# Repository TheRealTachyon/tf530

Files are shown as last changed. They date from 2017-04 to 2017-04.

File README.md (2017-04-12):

# Fork pulled by Tachyon to preserve the project. Commits accepted.
# Original file and comments follow
#  --------------------------------------------------------

# TF530 (Archived)

## I am no longer working on this. Do not ask for support.

This repository contains all the files needed to produce a copy of my accelerator board.

The CPLD Required is a XC9572XL-10VQ64

Everything in this repository is released under the GNU GPLv2. You may create or base commercial PCBs from the work in this repository but you must make the sources for all derivative work available. 

## Firmware / Requirements

  * Xilinx ISE, 14.7 (the final version - other versions may work but this is the one I support)
  * JTAG Adaptor

[For more information visit my channel](https://www.youtube.com/c/TerribleFire)

##License

This project and all the files contained are released under the GNU GPLv2. If you build a modified version of the board you must supply the end user with all the sources (this can be a web link).

##The TerribleFire 530 board (Revision 2)

This board is now in Beta. It may not work in all circumstances but it has been verified to boot AmigaOS 1.3, 2.05 and 3.1 and run various games and desktop apps at 25Mhz. Operation is not guarunteed to be crash free but will work in most "happy path" situations.

I have only verified the HD interface with Compact Flash cards.
I have verified this board boots on Amiga 500 Rev 5, 6a, 8.1a

I accept no responsibiltiy for any damage to any equipment that results from the use of this board. IT IS ENTIRELY AT YOUR OWN RISK!

## Installation

Installation is exactly the same as the Kipper2k A508. Refer to http://www.kipper2k.com/a500fastmem.html

You need to connect the OVR and INT2 signals to the A500 header port. 

## What does the board look like

Image of Top of PCB

Image of Bottom of PCB

## The BOM 

BOM converted to spreadsheet and now stored in DOCS (Tachyon)

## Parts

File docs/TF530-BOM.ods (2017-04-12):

TF530 Bill of Materials
Qty | Value | Device | Package | Parts | Description
1 |  | MC68030RC | MPGA128 | IC1 | Motorola 68030 CPU
1 |  | MC68881FN-SOC | PLCC68-S | IC2 | Motorola 68882(68881) FPU
1 | 10K | RESISTOR1206 | 1206 | R3 | Resistors
13 | 10uF | CAP_CERAMIC1206 | 1206 | C1, C2, C3, C4, C5, C6, C7, C8, C9, C10, C11, C12, C13 | Ceramic Capacitors
2 | 47K | RESISTOR1206 | 1206 | R1, R2 | Resistors
2 |  | 74LVC1G17DBV | SOT23-5 | IC4, IC5 | Single Schmitt-Trigger Buffer
1 | A500 | JUMPER-2PTH | 1X02 | A500 | Jumper
4 | 512K x 8 | AS7C4096A-12TCN | TSOP44-II | U$1, U$2, U$3, U$4 | SRAM 4M, 5V, 12ns, FAST 512K x 8 Asynch SRAM
1 | AUXPINS | JUMPER-2PTH | 1X02 | AUXPINS | Jumper
1 | BYPASS | JUMPER-2PTH | 1X02 | BYPASS | Jumper (optional)
3 | RESCAXE80P320X160-8N | CAY16-103J4LF |  | RN1, RN2, RN3 | Res Thick Film Array 10K Ohm
1 | CDIS | JUMPER-2PTH | 1X02 | JP5 | Jumper
1 | CLOCKSEL | JUMPER-3PTH | 1X03 | JP1 | Clock Select Jumper
1 | EXT5V | JUMPER-2PTH | 1X02 | JP7 | External 5v Power Source (optional)
1 | 40 | PINHD-2X20 | 2X20 | IDE | IDE header
1 | 6 | HEADER-1X6ROUND | 1X06_ROUND | JTAG | Header for JTAG port (firmware & Updates)
1 | 3.3V | V_REG_LM1117SOT223 | SOT223 | U1 | 3.3V Voltage Regulator LM1117
1 |  | MC68000P | DIL64 | X1 | 128pins PGA socket (13x13) for 68030
1 | MMUDIS | JUMPER-2PTH | 1X02 | JP3 | Jumper to disable MMU
1 | SPI PORT | PINHD-2X6 | 2X06 | SPIPORT | Dual SPI port headers (Future upgrades)
1 | X24MHZ | OSCILLATOR | OSC_7X5MM | OSC1 | Crystal Oscillator to drive accelerated clock domain (default 24MHz)
2 | XC9572XL-10VQ64 | XC9572XL-VQ64 | VQ64 | XC9572XL(BUS), XC9572XL(RAM) | Xilinx CPLD’s

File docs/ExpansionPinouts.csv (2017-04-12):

Amiga expansion connectors - 86 PIN EDGE
PIN | A500 | A1000 | A2000 | A2000b | FUNCTION
1 | x | x | x | x | ground
2 | x | x | x | x | ground
3 | x | x | x | x | ground
4 | x | x | x | x | ground
5 | x | x | x | x | +5VDC
6 | x | x | x | x | +5VDC
7 | x | x | x | x | No Connect
8 | x | x | x | x | -5VDC
9 | x | x | _ | _ | No Connect
 | _ | _ | x | x | 28MHz Clock
10 | x | x | x | x | +12VDC
11 | x | x | x | _ | No Connect
 | _ | _ | _ | x | /COPCFG (Configuration Out)
12 | x | x | x | x | CONFIG IN – Grounded
13 | x | x | x | x | Ground
14 | x | x | x | x | /C3 Clock
15 | x | x | x | x | CDAC Clock
16 | x | x | x | x | /C1 Clock
17 | x | x | x | x | /OVR
18 | x | x | x | x | RDY
19 | x | x | x | x | /INT2
20 | _ | x | _ | _ | /PALOPE
 | x | _ | x | _ | No Connect
 | _ | _ | _ | x | /BOSS
21 | x | x | x | x | A5
22 | x | x | x | x | /INT6
23 | x | x | x | x | A6
24 | x | x | x | x | A4
25 | x | x | x | x | ground
26 | x | x | x | x | A3
27 | x | x | x | x | A2
28 | x | x | x | x | A7
29 | x | x | x | x | A1
30 | x | x | x | x | A8
31 | x | x | x | x | FC0
32 | x | x | x | x | A9
33 | x | x | x | x | FC1
34 | x | x | x | x | A10
35 | x | x | x | x | FC2
36 | x | x | x | x | A11
37 | x | x | x | x | Ground
38 | x | x | x | x | A12
39 | x | x | x | x | A13
40 | x | x | x | x | /IPL0
41 | x | x | x | x | A14
42 | x | x | x | x | /IPL1
43 | x | x | x | x | A15
44 | x | x | x | x | /IPL2
45 | x | x | x | x | A16
46 | x | x | x | x | BEER*
47 | x | x | x | x | A17
48 | x | x | x | x | /VPA
49 | x | x | x | x | Ground
50 | x | x | x | x | E Clock
51 | x | x | x | x | /VMA
52 | x | x | x | x | A18
53 | x | x | x | x | RST
54 | x | x | x | x | Al9
55 | x | x | x | x | /HLT
56 | x | x | x | x | A20
57 | x | x | x | x | A22
58 | x | x | x | x | A21
59 | x | x | x | x | A23
60 | x | x | x | _ | /BR
 | _ | _ | _ | x | /CBR
61 | x | x | x | x | Ground
62 | x | x | x | x | /BGACK
63 | x | x | x | x | D15
64 | x | x | x | _ | /BG
 | _ | _ | _ | x | /CBG
65 | x | x | x | x | D14
66 | x | x | x | x | /DTACK
67 | x | x | x | x | D13
68 | x | x | x | x | R/W
69 | x | x | x | x | D12
70 | x | x | x | x | /LDS
71 | x | x | x | x | D11
72 | x | x | x | x | /UDS
73 | x | x | x | x | Ground
74 | x | x | x | x | /AS
75 | x | x | x | x | D0
76 | x | x | x | x | D10
77 | x | x | x | x | D1
78 | x | x | x | x | D9
79 | x | x | x | x | D2
80 | x | x | x | x | D8
81 | x | x | x | x | D3
82 | x | x | x | x | D7
83 | x | x | x | x | D4
84 | x | x | x | x | D6
85 | x | x | x | x | Ground
86 | x | x | x | x | D5

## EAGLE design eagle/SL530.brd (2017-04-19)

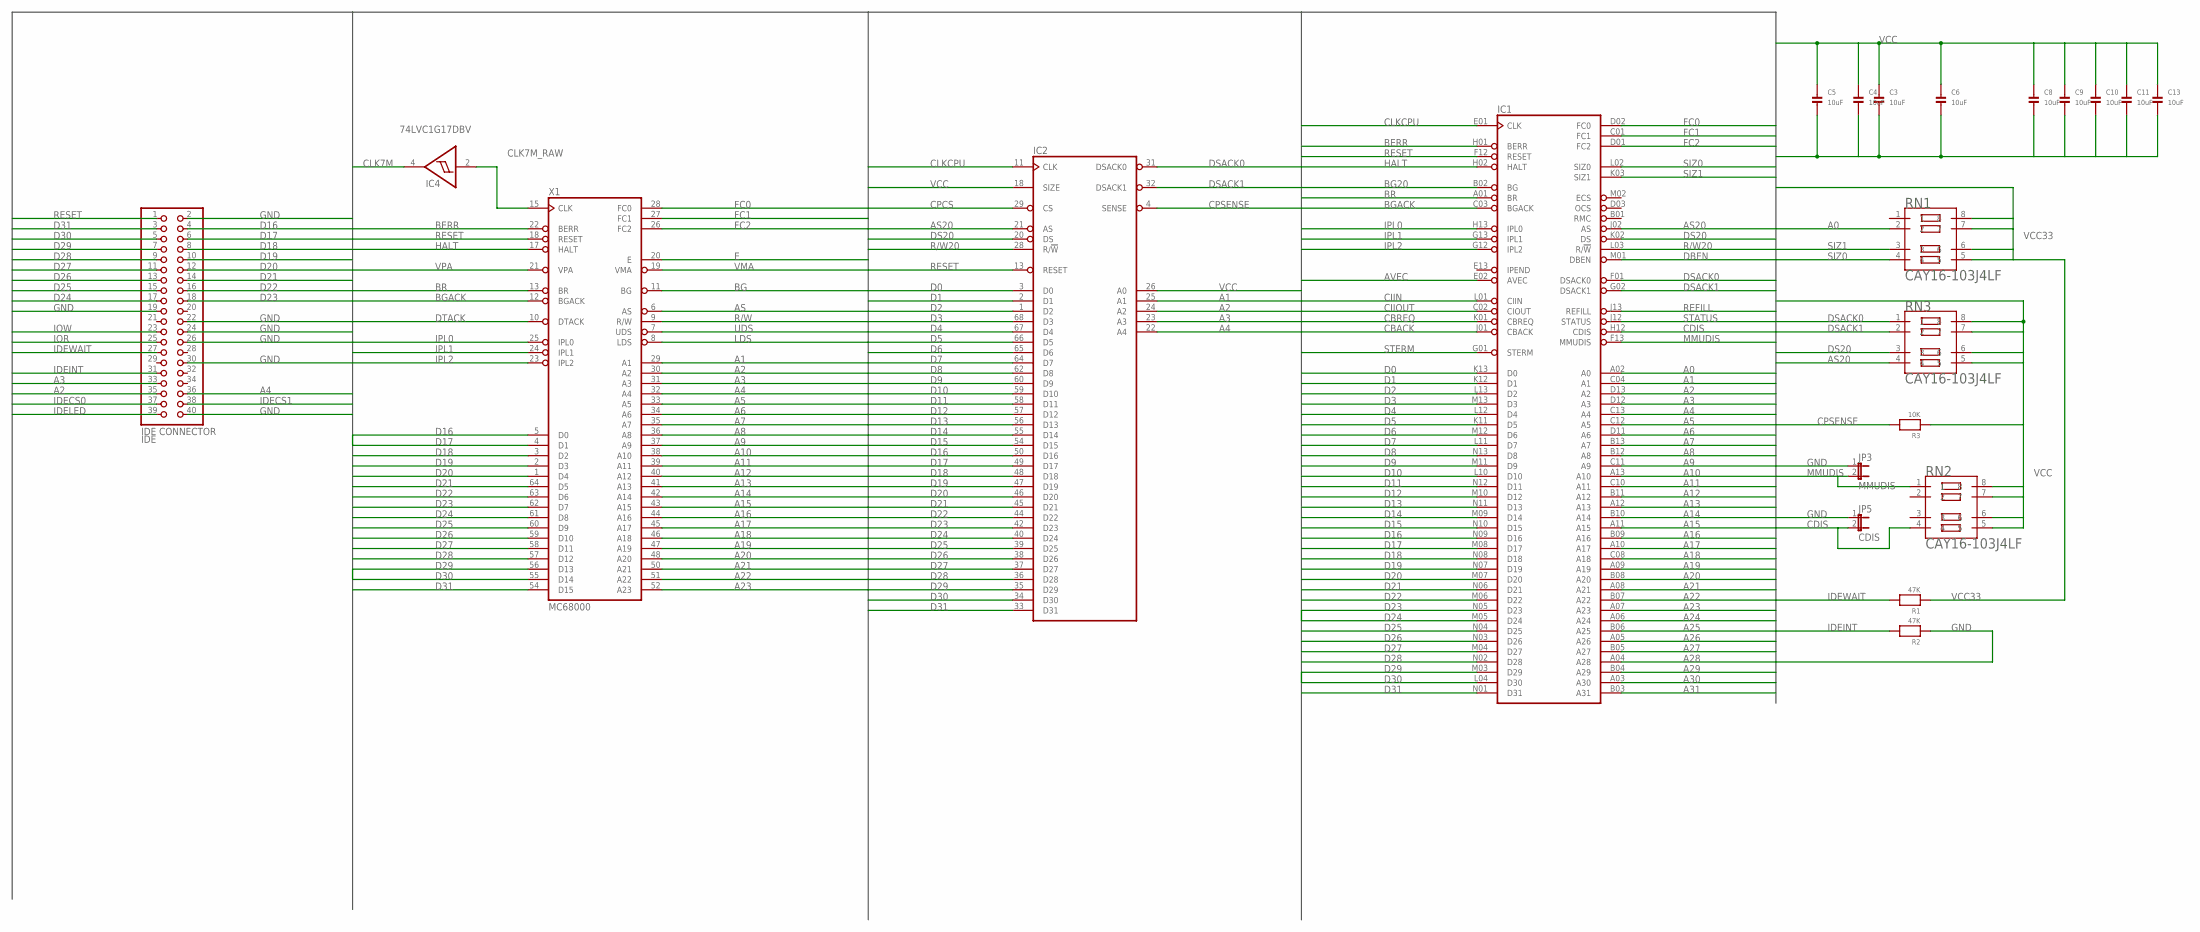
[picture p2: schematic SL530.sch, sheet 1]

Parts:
C3, C4, C5, C6, C8, C9, C10, C11, C13: 10uF; 1206
IC1: MC68030RC; MPGA128
IC2: MC68881FN-SOC; PLCC68-S
IC4: 74LVC1G17DBV; SOT23-5
IDE: IDE CONNECTOR; 2X20
JP3: MMUDIS; 1X02
JP5: CDIS; 1X02
R1, R2: 47K; 1206
R3: 10K; 1206
RN1, RN2, RN3: CAY16-103J4LF; RESCAXE80P320X160-8N
X1: MC68000; DIL64

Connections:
A0: IC1.A02 (A0), RN1.2; also elsewhere on the board
A1: IC1.C04 (A1), IC2.25 (A1), X1.29 (A1); also elsewhere on the board
A2: IC1.D13 (A2), IC2.24 (A2), IDE.35, X1.30 (A2); also elsewhere on the board
A3: IC1.D12 (A3), IC2.23 (A3), IDE.33, X1.31 (A3); also elsewhere on the board
A4: IC1.C13 (A4), IC2.22 (A4), IDE.36, X1.32 (A4); also elsewhere on the board
A5: IC1.C12 (A5), X1.33 (A5); also elsewhere on the board
A6: IC1.D11 (A6), X1.34 (A6); also elsewhere on the board
A7: IC1.B13 (A7), X1.35 (A7); also elsewhere on the board
A8: IC1.B12 (A8), X1.36 (A8); also elsewhere on the board
A9: IC1.C11 (A9), X1.37 (A9); also elsewhere on the board
A10: IC1.A13 (A10), X1.38 (A10); also elsewhere on the board
A11: IC1.C10 (A11), X1.39 (A11); also elsewhere on the board
A12: IC1.B11 (A12), X1.40 (A12); also elsewhere on the board
A13: IC1.A12 (A13), X1.41 (A13); also elsewhere on the board
A14: IC1.B10 (A14), X1.42 (A14); also elsewhere on the board
A15: IC1.A11 (A15), X1.43 (A15); also elsewhere on the board
A16: IC1.B09 (A16), X1.44 (A16); also elsewhere on the board
A17: IC1.A10 (A17), X1.45 (A17); also elsewhere on the board
A18: IC1.C08 (A18), X1.46 (A18); also elsewhere on the board
A19: IC1.A09 (A19), X1.47 (A19); also elsewhere on the board
A20: IC1.B08 (A20), X1.48 (A20); also elsewhere on the board
A21: IC1.A08 (A21), X1.50 (A21); also elsewhere on the board
A22: IC1.B07 (A22), X1.51 (A22); also elsewhere on the board
A23: IC1.A07 (A23), X1.52 (A23); also elsewhere on the board
A24: IC1.A06 (A24)
A25: IC1.B06 (A25)
A26: IC1.A05 (A26)
A27: IC1.B05 (A27)
A28: IC1.A04 (A28)
A29: IC1.B04 (A29)
A30: IC1.A03 (A30)
A31: IC1.B03 (A31)
AS: X1.6 (AS); also elsewhere on the board
AS20: IC1.J02 (AS), IC2.21 (AS), RN3.4; also elsewhere on the board
AVEC: IC1.E02 (AVEC); also elsewhere on the board
BERR: IC1.H01 (BERR), X1.22 (BERR); also elsewhere on the board
BG: X1.11 (BG); also elsewhere on the board
BG20: IC1.B02 (BG); also elsewhere on the board
BGACK: IC1.C03 (BGACK), X1.12 (BGACK); also elsewhere on the board
BR: IC1.A01 (BR), X1.13 (BR)
CBACK: IC1.J01 (CBACK); also elsewhere on the board
CBREQ: IC1.K01 (CBREQ); also elsewhere on the board
CDIS: IC1.H12 (CDIS), JP5.2, RN2.4
CIIN: IC1.L01 (CIIN); also elsewhere on the board
CIIOUT: IC1.C02 (CIOUT)
CLK7M: IC4.4 (O); also elsewhere on the board
CLK7M_RAW: IC4.2 (I), X1.15 (CLK)
CLKCPU: IC1.E01 (CLK), IC2.11 (CLK); also elsewhere on the board
CPCS: IC2.29 (CS); also elsewhere on the board
CPSENSE: IC2.4 (SENSE), R3.2; also elsewhere on the board
D0: IC1.K13 (D0), IC2.3 (D0); also elsewhere on the board
D1: IC1.K12 (D1), IC2.2 (D1); also elsewhere on the board
D2: IC1.L13 (D2), IC2.1 (D2); also elsewhere on the board
D3: IC1.M13 (D3), IC2.68 (D3); also elsewhere on the board
D4: IC1.L12 (D4), IC2.67 (D4); also elsewhere on the board
D5: IC1.K11 (D5), IC2.66 (D5); also elsewhere on the board
D6: IC1.M12 (D6), IC2.65 (D6); also elsewhere on the board
D7: IC1.L11 (D7), IC2.64 (D7); also elsewhere on the board
D8: IC1.N13 (D8), IC2.62 (D8); also elsewhere on the board
D9: IC1.M11 (D9), IC2.60 (D9); also elsewhere on the board
D10: IC1.L10 (D10), IC2.59 (D10); also elsewhere on the board
D11: IC1.N12 (D11), IC2.58 (D11); also elsewhere on the board
D12: IC1.M10 (D12), IC2.57 (D12); also elsewhere on the board
D13: IC1.N11 (D13), IC2.56 (D13); also elsewhere on the board
D14: IC1.M09 (D14), IC2.55 (D14); also elsewhere on the board
D15: IC1.N10 (D15), IC2.54 (D15); also elsewhere on the board
D16: IC1.N09 (D16), IC2.50 (D16), IDE.4, X1.5 (D0); also elsewhere on the board
D17: IC1.M08 (D17), IC2.49 (D17), IDE.6, X1.4 (D1); also elsewhere on the board
D18: IC1.N08 (D18), IC2.48 (D18), IDE.8, X1.3 (D2); also elsewhere on the board
D19: IC1.N07 (D19), IC2.47 (D19), IDE.10, X1.2 (D3); also elsewhere on the board
D20: IC1.M07 (D20), IC2.46 (D20), IDE.12, X1.1 (D4); also elsewhere on the board
D21: IC1.N06 (D21), IC2.45 (D21), IDE.14, X1.64 (D5); also elsewhere on the board
D22: IC1.M06 (D22), IC2.44 (D22), IDE.16, X1.63 (D6); also elsewhere on the board
D23: IC1.N05 (D23), IC2.42 (D23), IDE.18, X1.62 (D7); also elsewhere on the board
D24: IC1.M05 (D24), IC2.40 (D24), IDE.17, X1.61 (D8); also elsewhere on the board
D25: IC1.N04 (D25), IC2.39 (D25), IDE.15, X1.60 (D9); also elsewhere on the board
D26: IC1.N03 (D26), IC2.38 (D26), IDE.13, X1.59 (D10); also elsewhere on the board
D27: IC1.M04 (D27), IC2.37 (D27), IDE.11, X1.58 (D11); also elsewhere on the board
D28: IC1.N02 (D28), IC2.36 (D28), IDE.9, X1.57 (D12); also elsewhere on the board
D29: IC1.M03 (D29), IC2.35 (D29), IDE.7, X1.56 (D13); also elsewhere on the board
D30: IC1.L04 (D30), IC2.34 (D30), IDE.5, X1.55 (D14); also elsewhere on the board
D31: IC1.N01 (D31), IC2.33 (D31), IDE.3, X1.54 (D15); also elsewhere on the board
DBEN: IC1.M01 (DBEN)
DS20: IC1.K02 (DS), IC2.20 (DS), RN3.3; also elsewhere on the board
DSACK0: IC1.F01 (DSACK0), IC2.31 (DSACK0), RN3.1; also elsewhere on the board
DSACK1: IC1.G02 (DSACK1), IC2.32 (DSACK1), RN3.2; also elsewhere on the board
DTACK: X1.10 (DTACK); also elsewhere on the board
E: X1.20 (E); also elsewhere on the board
FC0: IC1.D02 (FC0), X1.28 (FC0); also elsewhere on the board
FC1: IC1.C01 (FC1), X1.27 (FC1); also elsewhere on the board
FC2: IC1.D01 (FC2), X1.26 (FC2); also elsewhere on the board
GND: C3.2, C4.2, C5.2, C6.2, C8.2, C9.2, C10.2, C11.2, C13.2, IC1.C05 (GND), IC1.C07 (GND), IC1.C09 (GND), IC1.E03 (GND), IC1.E11 (GND), IC1.F03 (GND), IC1.G03 (GND), IC1.G11 (GND), IC1.J03 (GND), IC1.J11 (GND), IC1.L05 (GND), IC1.L07 (GND), IC1.L08 (GND), IC1.L09 (GND), IC2.5 (GND), IC2.6 (GND), IC2.7 (GND), IC2.8 (GND), IC2.9 (GND), IC2.12 (GND), IC2.14 (GND), IC2.19 (GND), IC2.30 (GND), IC2.41 (GND), IC2.51 (GND), IC2.63 (GND), IC4.3 (GND), IDE.2, IDE.19, IDE.22, IDE.24, IDE.26, IDE.30, IDE.40, JP3.1, JP5.1, R2.1, X1.16 (GND), X1.53 (GND); also elsewhere on the board
HALT: IC1.H02 (HALT), X1.17 (HALT); also elsewhere on the board
IDECS0: IDE.37; also elsewhere on the board
IDECS1: IDE.38; also elsewhere on the board
IDEINT: IDE.31, R2.2; also elsewhere on the board
IDELED: IDE.39
IDEWAIT: IDE.27, R1.2; also elsewhere on the board
IOR: IDE.25; also elsewhere on the board
IOW: IDE.23; also elsewhere on the board
IPL0: IC1.H13 (IPL0), X1.25 (IPL0)
IPL1: IC1.G13 (IPL1), X1.24 (IPL1)
IPL2: IC1.G12 (IPL2), X1.23 (IPL2)
LDS: X1.8 (LDS); also elsewhere on the board
MMUDIS: IC1.F13 (MMUDIS), JP3.2, RN2.1
R/W: X1.9 (R/W); also elsewhere on the board
R/W20: IC1.L03 (R/!W), IC2.28 (R/!W); also elsewhere on the board
REFILL: IC1.J13 (REFILL)
RESET: IC1.F12 (RESET), IC2.13 (RESET), IDE.1, X1.18 (RESET); also elsewhere on the board
SIZ0: IC1.L02 (SIZ0), RN1.4; also elsewhere on the board
SIZ1: IC1.K03 (SIZ1), RN1.3; also elsewhere on the board
STATUS: IC1.J12 (STATUS)
STERM: IC1.G01 (STERM); also elsewhere on the board
UDS: X1.7 (UDS); also elsewhere on the board
VCC: C3.1, C4.1, C5.1, C6.1, C8.1, C9.1, C10.1, C11.1, C13.1, IC1.C06 (VCC), IC1.D04 (VCC), IC1.D10 (VCC), IC1.F02 (VCC), IC1.F11 (VCC), IC1.H03 (VCC), IC1.H11 (VCC), IC1.K04 (VCC), IC1.K10 (VCC), IC1.L06 (VCC), IC2.10 (VCC), IC2.16 (VCC), IC2.17 (VCC), IC2.18 (SIZE), IC2.26 (A0), IC2.27 (VCC), IC2.43 (VCC), IC2.52 (VCC), IC2.53 (VCC), IC2.61 (VCC), IC4.5 (VCC), R3.1, RN2.5, RN2.6, RN2.7, RN2.8, RN3.5, RN3.6, RN3.7, RN3.8, X1.14 (VCC), X1.49 (VCC); also elsewhere on the board
VCC33: R1.1, RN1.5, RN1.6, RN1.7, RN1.8; also elsewhere on the board
VMA: X1.19 (VMA); also elsewhere on the board
VPA: X1.21 (VPA); also elsewhere on the board

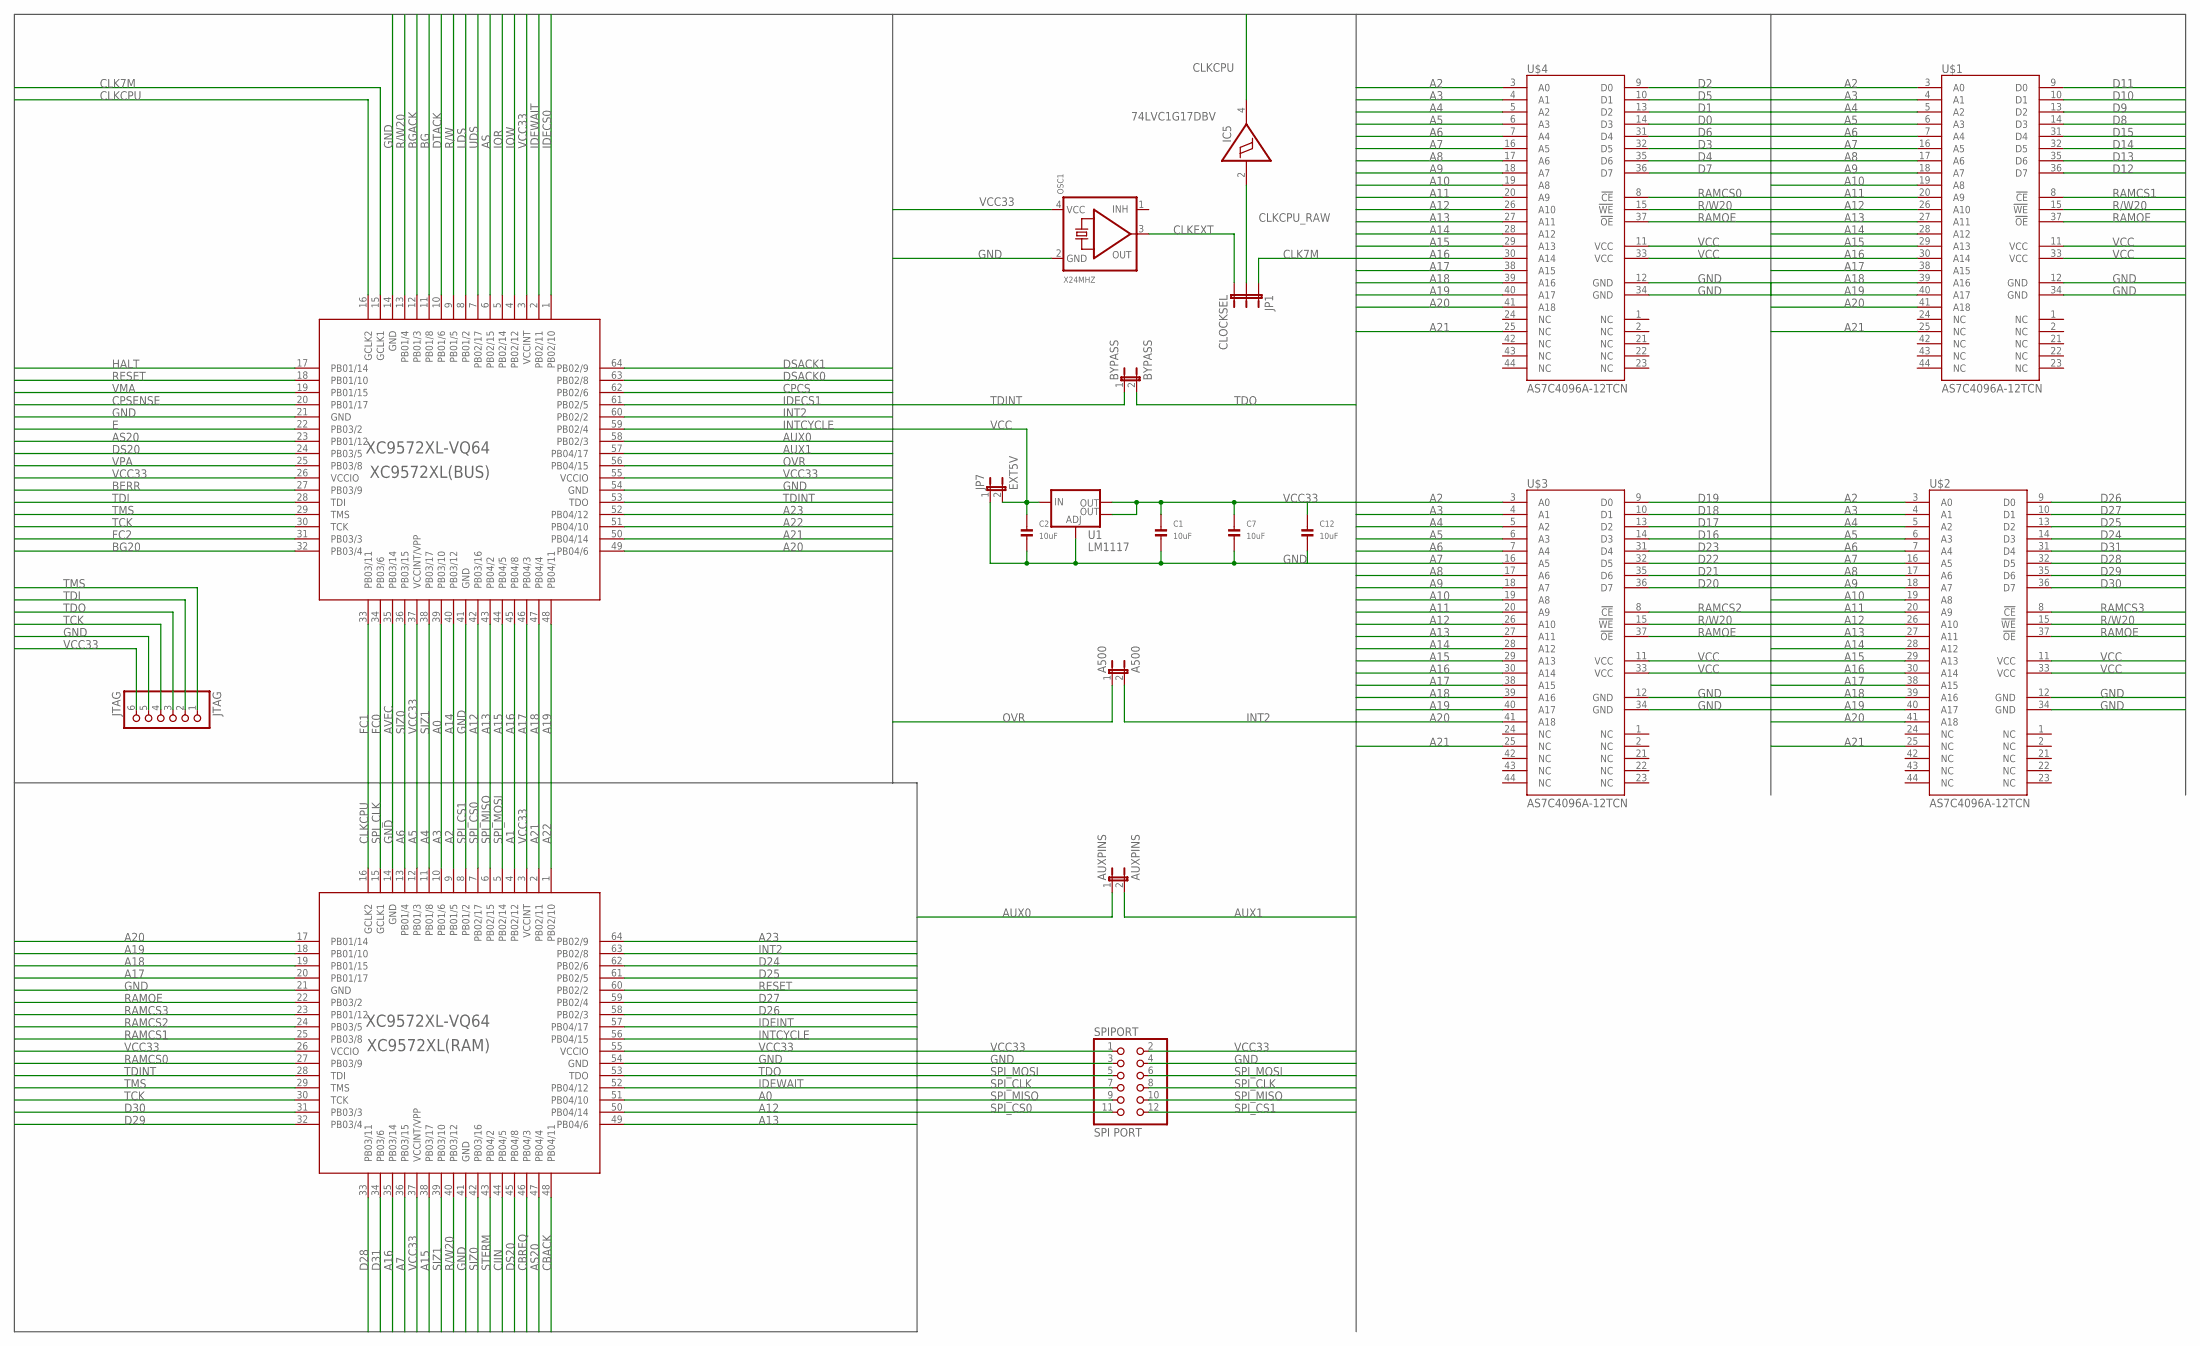
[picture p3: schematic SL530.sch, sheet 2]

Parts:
A500: A500; 1X02
AUXPINS: AUXPINS; 1X02
BYPASS: BYPASS; 1X02
C1, C2, C7, C12: 10uF; 1206
IC5: 74LVC1G17DBV; SOT23-5
JP1: CLOCKSEL; 1X03
JP7: EXT5V; 1X02
JTAG: JTAG; 1X06_ROUND
OSC1: X24MHZ; OSC_7X5MM
SPIPORT: SPI PORT; 2X06
U1: LM1117; SOT223
U$1, U$2, U$3, U$4: AS7C4096A-12TCN; TSOP44-II
XC9572XL(BUS), XC9572XL(RAM): XC9572XL-VQ64; VQ64

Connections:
A0: XC9572XL(BUS).39 (PB03/10), XC9572XL(RAM).51 (PB04/10); also elsewhere on the board
A1: XC9572XL(RAM).4 (PB02/12); also elsewhere on the board
A2: U$1.3 (A0), U$2.3 (A0), U$3.3 (A0), U$4.3 (A0), XC9572XL(RAM).9 (PB01/5); also elsewhere on the board
A3: U$1.4 (A1), U$2.4 (A1), U$3.4 (A1), U$4.4 (A1), XC9572XL(RAM).10 (PB01/6); also elsewhere on the board
A4: U$1.5 (A2), U$2.5 (A2), U$3.5 (A2), U$4.5 (A2), XC9572XL(RAM).11 (PB01/8); also elsewhere on the board
A5: U$1.6 (A3), U$2.6 (A3), U$3.6 (A3), U$4.6 (A3), XC9572XL(RAM).12 (PB01/3); also elsewhere on the board
A6: U$1.7 (A4), U$2.7 (A4), U$3.7 (A4), U$4.7 (A4), XC9572XL(RAM).13 (PB01/4); also elsewhere on the board
A7: U$1.16 (A5), U$2.16 (A5), U$3.16 (A5), U$4.16 (A5), XC9572XL(RAM).36 (PB03/15); also elsewhere on the board
A8: U$1.17 (A6), U$2.17 (A6), U$3.17 (A6), U$4.17 (A6); also elsewhere on the board
A9: U$1.18 (A7), U$2.18 (A7), U$3.18 (A7), U$4.18 (A7); also elsewhere on the board
A10: U$1.19 (A8), U$2.19 (A8), U$3.19 (A8), U$4.19 (A8); also elsewhere on the board
A11: U$1.20 (A9), U$2.20 (A9), U$3.20 (A9), U$4.20 (A9); also elsewhere on the board
A12: U$1.26 (A10), U$2.26 (A10), U$3.26 (A10), U$4.26 (A10), XC9572XL(BUS).42 (PB03/16), XC9572XL(RAM).50 (PB04/14); also elsewhere on the board
A13: U$1.27 (A11), U$2.27 (A11), U$3.27 (A11), U$4.27 (A11), XC9572XL(BUS).43 (PB04/2), XC9572XL(RAM).49 (PB04/6); also elsewhere on the board
A14: U$1.28 (A12), U$2.28 (A12), U$3.28 (A12), U$4.28 (A12), XC9572XL(BUS).40 (PB03/12); also elsewhere on the board
A15: U$1.29 (A13), U$2.29 (A13), U$3.29 (A13), U$4.29 (A13), XC9572XL(BUS).44 (PB04/5), XC9572XL(RAM).38 (PB03/17); also elsewhere on the board
A16: U$1.30 (A14), U$2.30 (A14), U$3.30 (A14), U$4.30 (A14), XC9572XL(BUS).45 (PB04/8), XC9572XL(RAM).35 (PB03/14); also elsewhere on the board
A17: U$1.38 (A15), U$2.38 (A15), U$3.38 (A15), U$4.38 (A15), XC9572XL(BUS).46 (PB04/3), XC9572XL(RAM).20 (PB01/17); also elsewhere on the board
A18: U$1.39 (A16), U$2.39 (A16), U$3.39 (A16), U$4.39 (A16), XC9572XL(BUS).47 (PB04/4), XC9572XL(RAM).19 (PB01/15); also elsewhere on the board
A19: U$1.40 (A17), U$2.40 (A17), U$3.40 (A17), U$4.40 (A17), XC9572XL(BUS).48 (PB04/11), XC9572XL(RAM).18 (PB01/10); also elsewhere on the board
A20: U$1.41 (A18), U$2.41 (A18), U$3.41 (A18), U$4.41 (A18), XC9572XL(BUS).49 (PB04/6), XC9572XL(RAM).17 (PB01/14); also elsewhere on the board
A21: U$1.25 (NC), U$2.25 (NC), U$3.25 (NC), U$4.25 (NC), XC9572XL(BUS).50 (PB04/14), XC9572XL(RAM).2 (PB02/11); also elsewhere on the board
A22: XC9572XL(BUS).51 (PB04/10), XC9572XL(RAM).1 (PB02/10); also elsewhere on the board
A23: XC9572XL(BUS).52 (PB04/12), XC9572XL(RAM).64 (PB02/9); also elsewhere on the board
AS: XC9572XL(BUS).6 (PB02/15); also elsewhere on the board
AS20: XC9572XL(BUS).23 (PB01/12), XC9572XL(RAM).47 (PB04/4); also elsewhere on the board
AUX0: AUXPINS.1, XC9572XL(BUS).58 (PB02/3)
AUX1: AUXPINS.2, XC9572XL(BUS).57 (PB04/17)
AVEC: XC9572XL(BUS).35 (PB03/14); also elsewhere on the board
BERR: XC9572XL(BUS).27 (PB03/9); also elsewhere on the board
BG: XC9572XL(BUS).11 (PB01/8); also elsewhere on the board
BG20: XC9572XL(BUS).32 (PB03/4); also elsewhere on the board
BGACK: XC9572XL(BUS).12 (PB01/3); also elsewhere on the board
CBACK: XC9572XL(RAM).48 (PB04/11); also elsewhere on the board
CBREQ: XC9572XL(RAM).46 (PB04/3); also elsewhere on the board
CIIN: XC9572XL(RAM).44 (PB04/5); also elsewhere on the board
CLK7M: JP1.1, XC9572XL(BUS).15 (GCLK1); also elsewhere on the board
CLKCPU: IC5.4 (O), XC9572XL(BUS).16 (GCLK2), XC9572XL(RAM).16 (GCLK2); also elsewhere on the board
CLKCPU_RAW: IC5.2 (I), JP1.2
CLKEXT: JP1.3, OSC1.3 (OUT)
CPCS: XC9572XL(BUS).62 (PB02/6); also elsewhere on the board
CPSENSE: XC9572XL(BUS).20 (PB01/17); also elsewhere on the board
D0: U$4.14 (D3); also elsewhere on the board
D1: U$4.13 (D2); also elsewhere on the board
D2: U$4.9 (D0); also elsewhere on the board
D3: U$4.32 (D5); also elsewhere on the board
D4: U$4.35 (D6); also elsewhere on the board
D5: U$4.10 (D1); also elsewhere on the board
D6: U$4.31 (D4); also elsewhere on the board
D7: U$4.36 (D7); also elsewhere on the board
D8: U$1.14 (D3); also elsewhere on the board
D9: U$1.13 (D2); also elsewhere on the board
D10: U$1.10 (D1); also elsewhere on the board
D11: U$1.9 (D0); also elsewhere on the board
D12: U$1.36 (D7); also elsewhere on the board
D13: U$1.35 (D6); also elsewhere on the board
D14: U$1.32 (D5); also elsewhere on the board
D15: U$1.31 (D4); also elsewhere on the board
D16: U$3.14 (D3); also elsewhere on the board
D17: U$3.13 (D2); also elsewhere on the board
D18: U$3.10 (D1); also elsewhere on the board
D19: U$3.9 (D0); also elsewhere on the board
D20: U$3.36 (D7); also elsewhere on the board
D21: U$3.35 (D6); also elsewhere on the board
D22: U$3.32 (D5); also elsewhere on the board
D23: U$3.31 (D4); also elsewhere on the board
D24: U$2.14 (D3), XC9572XL(RAM).62 (PB02/6); also elsewhere on the board
D25: U$2.13 (D2), XC9572XL(RAM).61 (PB02/5); also elsewhere on the board
D26: U$2.9 (D0), XC9572XL(RAM).58 (PB02/3); also elsewhere on the board
D27: U$2.10 (D1), XC9572XL(RAM).59 (PB02/4); also elsewhere on the board
D28: U$2.32 (D5), XC9572XL(RAM).33 (PB03/11); also elsewhere on the board
D29: U$2.35 (D6), XC9572XL(RAM).32 (PB03/4); also elsewhere on the board
D30: U$2.36 (D7), XC9572XL(RAM).31 (PB03/3); also elsewhere on the board
D31: U$2.31 (D4), XC9572XL(RAM).34 (PB03/6); also elsewhere on the board
DS20: XC9572XL(BUS).24 (PB03/5), XC9572XL(RAM).45 (PB04/8); also elsewhere on the board
DSACK0: XC9572XL(BUS).63 (PB02/8); also elsewhere on the board
DSACK1: XC9572XL(BUS).64 (PB02/9); also elsewhere on the board
DTACK: XC9572XL(BUS).10 (PB01/6); also elsewhere on the board
E: XC9572XL(BUS).22 (PB03/2); also elsewhere on the board
FC0: XC9572XL(BUS).34 (PB03/6); also elsewhere on the board
FC1: XC9572XL(BUS).33 (PB03/11); also elsewhere on the board
FC2: XC9572XL(BUS).31 (PB03/3); also elsewhere on the board
GND: C1.2, C2.2, C7.2, C12.2, IC5.3 (GND), JP7.1, JTAG.5, OSC1.2 (GND), SPIPORT.3, SPIPORT.4, U1.1 (ADJ), U$1.12 (GND), U$1.34 (GND), U$2.12 (GND), U$2.34 (GND), U$3.12 (GND), U$3.34 (GND), U$4.12 (GND), U$4.34 (GND), XC9572XL(BUS).14 (GND), XC9572XL(BUS).21 (GND), XC9572XL(BUS).41 (GND), XC9572XL(BUS).54 (GND), XC9572XL(RAM).14 (GND), XC9572XL(RAM).21 (GND), XC9572XL(RAM).41 (GND), XC9572XL(RAM).54 (GND); also elsewhere on the board
HALT: XC9572XL(BUS).17 (PB01/14); also elsewhere on the board
IDECS0: XC9572XL(BUS).1 (PB02/10); also elsewhere on the board
IDECS1: XC9572XL(BUS).61 (PB02/5); also elsewhere on the board
IDEINT: XC9572XL(RAM).57 (PB04/17); also elsewhere on the board
IDEWAIT: XC9572XL(BUS).2 (PB02/11), XC9572XL(RAM).52 (PB04/12); also elsewhere on the board
INT2: A500.2, XC9572XL(BUS).60 (PB02/2), XC9572XL(RAM).63 (PB02/8)
INTCYCLE: XC9572XL(BUS).59 (PB02/4), XC9572XL(RAM).56 (PB04/15)
IOR: XC9572XL(BUS).5 (PB02/14); also elsewhere on the board
IOW: XC9572XL(BUS).4 (PB02/12); also elsewhere on the board
LDS: XC9572XL(BUS).8 (PB01/2); also elsewhere on the board
OVR: A500.1, XC9572XL(BUS).56 (PB04/15)
R/W: XC9572XL(BUS).9 (PB01/5); also elsewhere on the board
R/W20: U$1.15 (!WE), U$2.15 (!WE), U$3.15 (!WE), U$4.15 (!WE), XC9572XL(BUS).13 (PB01/4), XC9572XL(RAM).40 (PB03/12); also elsewhere on the board
RAMCS0: U$4.8 (!CE), XC9572XL(RAM).27 (PB03/9)
RAMCS1: U$1.8 (!CE), XC9572XL(RAM).25 (PB03/8)
RAMCS2: U$3.8 (!CE), XC9572XL(RAM).24 (PB03/5)
RAMCS3: U$2.8 (!CE), XC9572XL(RAM).23 (PB01/12)
RAMOE: U$1.37 (!OE), U$2.37 (!OE), U$3.37 (!OE), U$4.37 (!OE), XC9572XL(RAM).22 (PB03/2)
RESET: XC9572XL(BUS).18 (PB01/10), XC9572XL(RAM).60 (PB02/2); also elsewhere on the board
SIZ0: XC9572XL(BUS).36 (PB03/15), XC9572XL(RAM).42 (PB03/16); also elsewhere on the board
SIZ1: XC9572XL(BUS).38 (PB03/17), XC9572XL(RAM).39 (PB03/10); also elsewhere on the board
SPI_CLK: SPIPORT.7, SPIPORT.8, XC9572XL(RAM).15 (GCLK1)
SPI_CS0: SPIPORT.11, XC9572XL(RAM).7 (PB02/17)
SPI_CS1: SPIPORT.12, XC9572XL(RAM).8 (PB01/2)
SPI_MISO: SPIPORT.9, SPIPORT.10, XC9572XL(RAM).6 (PB02/15)
SPI_MOSI: SPIPORT.5, SPIPORT.6, XC9572XL(RAM).5 (PB02/14)
STERM: XC9572XL(RAM).43 (PB04/2); also elsewhere on the board
TCK: JTAG.4, XC9572XL(BUS).30 (TCK), XC9572XL(RAM).30 (TCK)
TDI: JTAG.2, XC9572XL(BUS).28 (TDI)
TDINT: BYPASS.1, XC9572XL(BUS).53 (TDO), XC9572XL(RAM).28 (TDI)
TDO: BYPASS.2, JTAG.3, XC9572XL(RAM).53 (TDO)
TMS: JTAG.1, XC9572XL(BUS).29 (TMS), XC9572XL(RAM).29 (TMS)
UDS: XC9572XL(BUS).7 (PB02/17); also elsewhere on the board
VCC: C2.1, IC5.5 (VCC), JP7.2, U1.3 (IN), U$1.11 (VCC), U$1.33 (VCC), U$2.11 (VCC), U$2.33 (VCC), U$3.11 (VCC), U$3.33 (VCC), U$4.11 (VCC), U$4.33 (VCC); also elsewhere on the board
VCC33: C1.1, C7.1, C12.1, JTAG.6, OSC1.4 (VCC), SPIPORT.1, SPIPORT.2, U1.2 (OUT), U1.4 (OUT), XC9572XL(BUS).3 (VCCINT), XC9572XL(BUS).26 (VCCIO), XC9572XL(BUS).37 (VCCINT/VPP), XC9572XL(BUS).55 (VCCIO), XC9572XL(RAM).3 (VCCINT), XC9572XL(RAM).26 (VCCIO), XC9572XL(RAM).37 (VCCINT/VPP), XC9572XL(RAM).55 (VCCIO); also elsewhere on the board
VMA: XC9572XL(BUS).19 (PB01/15); also elsewhere on the board
VPA: XC9572XL(BUS).25 (PB03/8); also elsewhere on the board

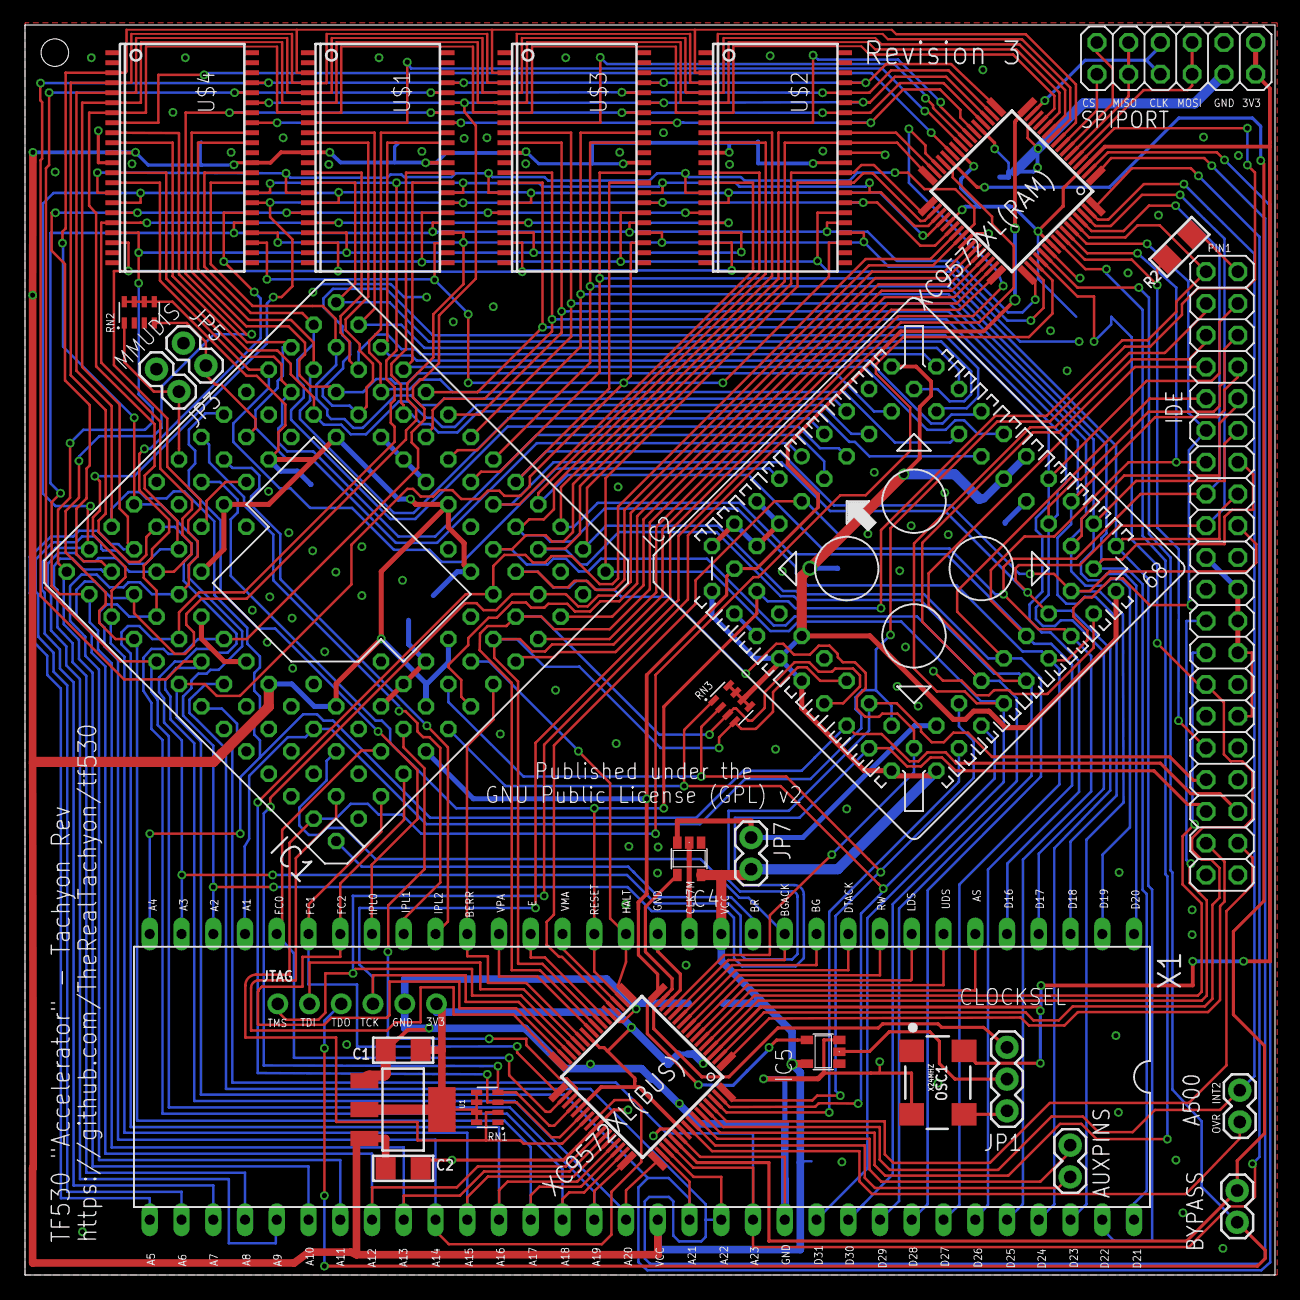
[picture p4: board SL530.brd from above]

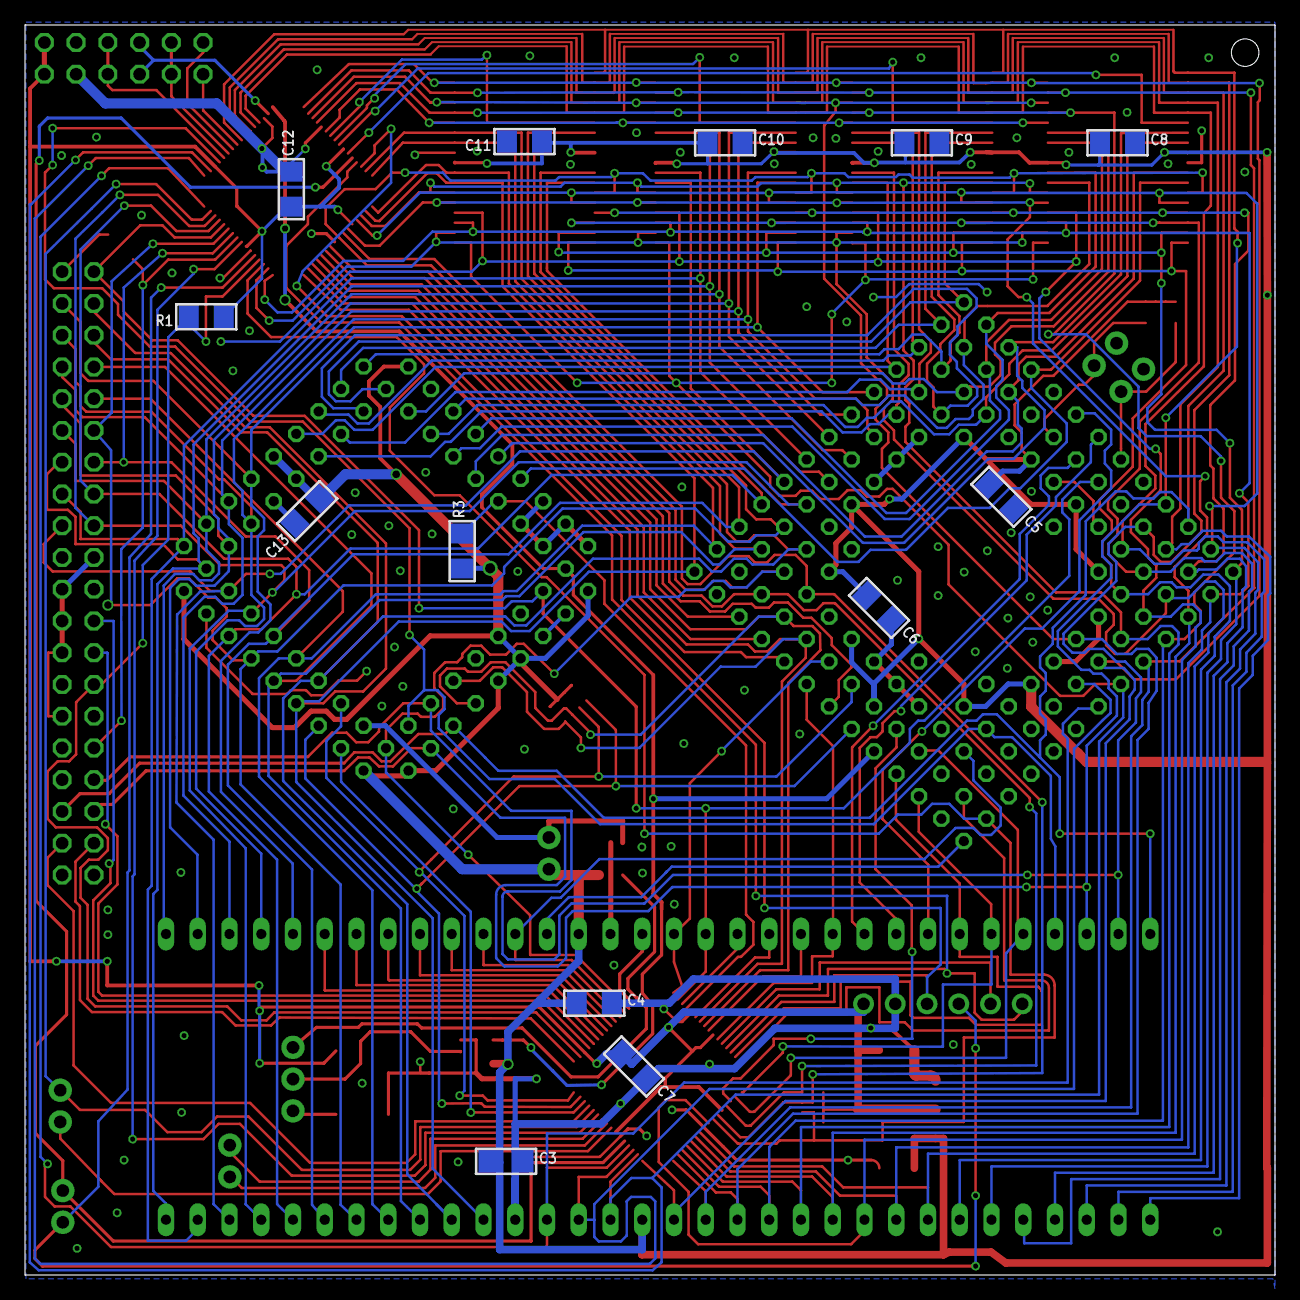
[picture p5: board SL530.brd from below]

Board: 2 copper layers, 100.0 x 100.0 mm, 42 parts (13 on the bottom side), 127 nets.

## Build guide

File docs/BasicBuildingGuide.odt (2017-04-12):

Let me make a few suggestions for building testing the TF530 boards.

Tools and test equipment

1) If you don't have an oscilloscope buy one ￼

1a) Ok serious, a logic probe is very useful for testing logic circuits and much cheaper, less than £10 on ebay.

They allow you to see logic levels and will tell you if a signal is pulsing or oscillating. This allows you

to see if a clock is oscillating or an address/data line is toggling. They can also help with some PSU issues. A quick guide to logic probes, http://wiki.arcadeotaku.com/w/Logic_Probe_Guide or https://pinside.com/pinball/forum/to...o-logic-probes

2) A microscope is great but expensive. I have one of the USB microscopes, costs around £30, resolution is good for joint inspection. A jewellers eye-glass with x12 or better magnification is great for inspecting solder joints.

3) Leaded solder 'wets' joints better than lead free solder. I can hand solder TQFP devices with minimal flux with lead solder, whereas with lead-free I need plenty of flux. Your favourite auction site has 'fine solder wire'. It is not illegal to purchase leaded solder but you can not sell a commercial product containing it (RoHS).

Debugging the boards

A microprocessor system needs 4 things to work, power, clock(s), configuration and a reset. Get these right and it should work. Achieving this is the challenge.

Power

Start with the power. The design takes 5V from the MC68000 socket. With the board plugged into the Amiga, power up and measure the voltage across JP7, the EXT5V jumper. You should have 4.85 to 5.15V. If it is outside of this range, weird things will happen. Someone will shout and tell me 5V devices can operate from 4.5-5.5V or 4.75 to 5.25V. Yes they can on their absolute maximums, I want a tighter spec for less future problems.

If the supply is too low, check the +5V on the AMiga, you can measure it at the Amiga PSU connector, http://www.ianstedman.co.uk/Amiga/am..._power_pcb.gif

Try cleaning the pins fo the 68000 socket on the AMiga with contact cleaner as they may be slightly corroded with age. Please don't use WD40!

If the supply is still low at the connector, you may need a replacement. Should I post a link to my ATX adaptors? ￼

On the TF530 is a 3.3V regulator, U1. Measuring across C2 with a Digital Multi-Meter(DMM), do you have 3.20-3.40V?

The 3.3V supply powers the oscillator (more on this later) and the two CPLDs.

Clocks

There are a few critical parameters here.

This design uses a crystal oscillator, not a crystal! If you buy a crystal, it will not work. The oscillator has the crystal, tank circuit and a buffer to drive TTL logic built into the can.

Make sure you buy a 3.3V part. A 5V part will work but the frequency output will wander and is not recommended. You are looking for one with TTL or CMOS output drive, tolerance of 50ppm, in the common 7x5mm can. You also want a fundamental mode output.

The next important parts are the 74LVC1G17DBV schmitt buffer devices. They performs two functions, it converts the 3.3V clock to a 5V signal and it speeds up the edges. The MC68030, requires a clock input with rise and fall times of <2ns for operation at 40 MHz, the chosen device has rise/fall times of 1.5ns. Most oscillators have rise/fall times of 5-10ns. If the clock input is too slow, the CPU and the Xilinx CPLDs, will fail to lock on and operate. IC4 buffers the 7MHz clock from the Amiga, IC5 the 24MHz clock from the onboard oscillator.

Use the oscilloscope or logic probe to check this is working. The clock goes to the CPU and both CPLDs, make sure it gets there, pin 16 of both the RAM and BUS CPLD.

Reset

Any digital system needs a power on reset and a hard reset at times. The Amiga provides the reset via the MC68000 slot and it goes to the MC68030 and the CPLDs, pin 60 of the RAM CPLD and pin 18 of the BUS CPLD. It should be low, briefly during power up and high/logic 1 during normal use. Check your soldering if it is not.

Configuration

With the MC68030, there are fewer configuration pins compared to modern CPUs but we can still check them. The Xilinx CPLDs also need programming and a few bits to configure them.

The Xilinx XC9574 CPLDs are easy to use compared to the Spartan/Virtex/Kintex FPGAs. They need a functional 3.3V supply, that is provided by U1 which you checked earlier. This supply should be functional within 50ms of the 5V supply being nominal. You would need to measure this with an oscilloscope.

The Reset to the device was covered previously as were the clocks for the internal logic. If the devices program and verify using the Xilinx Impact tool, they should be good to go. If you have issues programming them, slow down TCK at the programmer.

The MC68030 has two jumpers, JP3 (MMU disable) and JP5 (Cache Disable). Both should not be fitted for normal operation. Check the soldering of RN2 and that the pin 2 of both jumpers has a voltage >2.0V (logic 1).

Check the /HALT signal at pin 17 of the 68000 socket is logic 1.

Check the /BERR signal at pin 22 of the 68000 socket is logic 1.

Have you connected the OVR and INT2 wires correctly?

The Autoconfig logic is not something I can easily answer questions on, before delving too deep, check the basics detailed above first. If the system boots, try showconfig or whichamiga to see what is reported to the operating system.

This is a starting guide, feel free to distribute and to add information too.

Ian Stedman, http://www.ianstedman.co.uk

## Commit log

2017-04-12 Add files via upload
    Updated BOM in Spreadsheet form. Open document type (.ods / OASIS)
    Converted by Tachyon
    [TF530-BOM.ods]
2017-04-12 Add files via upload
    Diagram showing the jumper wires needed from the A500 expansion slot to the TF530
2017-04-19 Add files via upload
    Alternate jumper pad location for picking up _INT2 and _OVR on an Amiga 500 Plus motherboard.
    I would use 2 of the pairs from some twisted pair cable to make this jumper wire. I would take the solid colour of each pair and connect them each to one of the signals. I would then take the striped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
2017-04-19 Add files via upload
    Collected updates combined
    [SL530.brd, SL530.sch]

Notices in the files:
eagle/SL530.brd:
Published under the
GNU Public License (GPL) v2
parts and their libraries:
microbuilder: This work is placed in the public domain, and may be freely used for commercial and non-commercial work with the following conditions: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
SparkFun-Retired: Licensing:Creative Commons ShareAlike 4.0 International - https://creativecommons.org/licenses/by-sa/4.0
